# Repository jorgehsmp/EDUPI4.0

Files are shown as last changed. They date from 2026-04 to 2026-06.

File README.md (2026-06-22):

# EDUPI4.0

**PLC educativo, modular y de bajo coste basado en Raspberry Pi Zero 2 W.**

EDUPI4.0 acerca la automatización industrial a aulas, talleres y laboratorios mediante una plataforma abierta que combina entradas de 24 V, salidas por relé, conectividad y una carcasa imprimible en 3D. El repositorio reúne el diseño electrónico, la lista de materiales, el conjunto mecánico y evidencias de su evaluación en el aula.

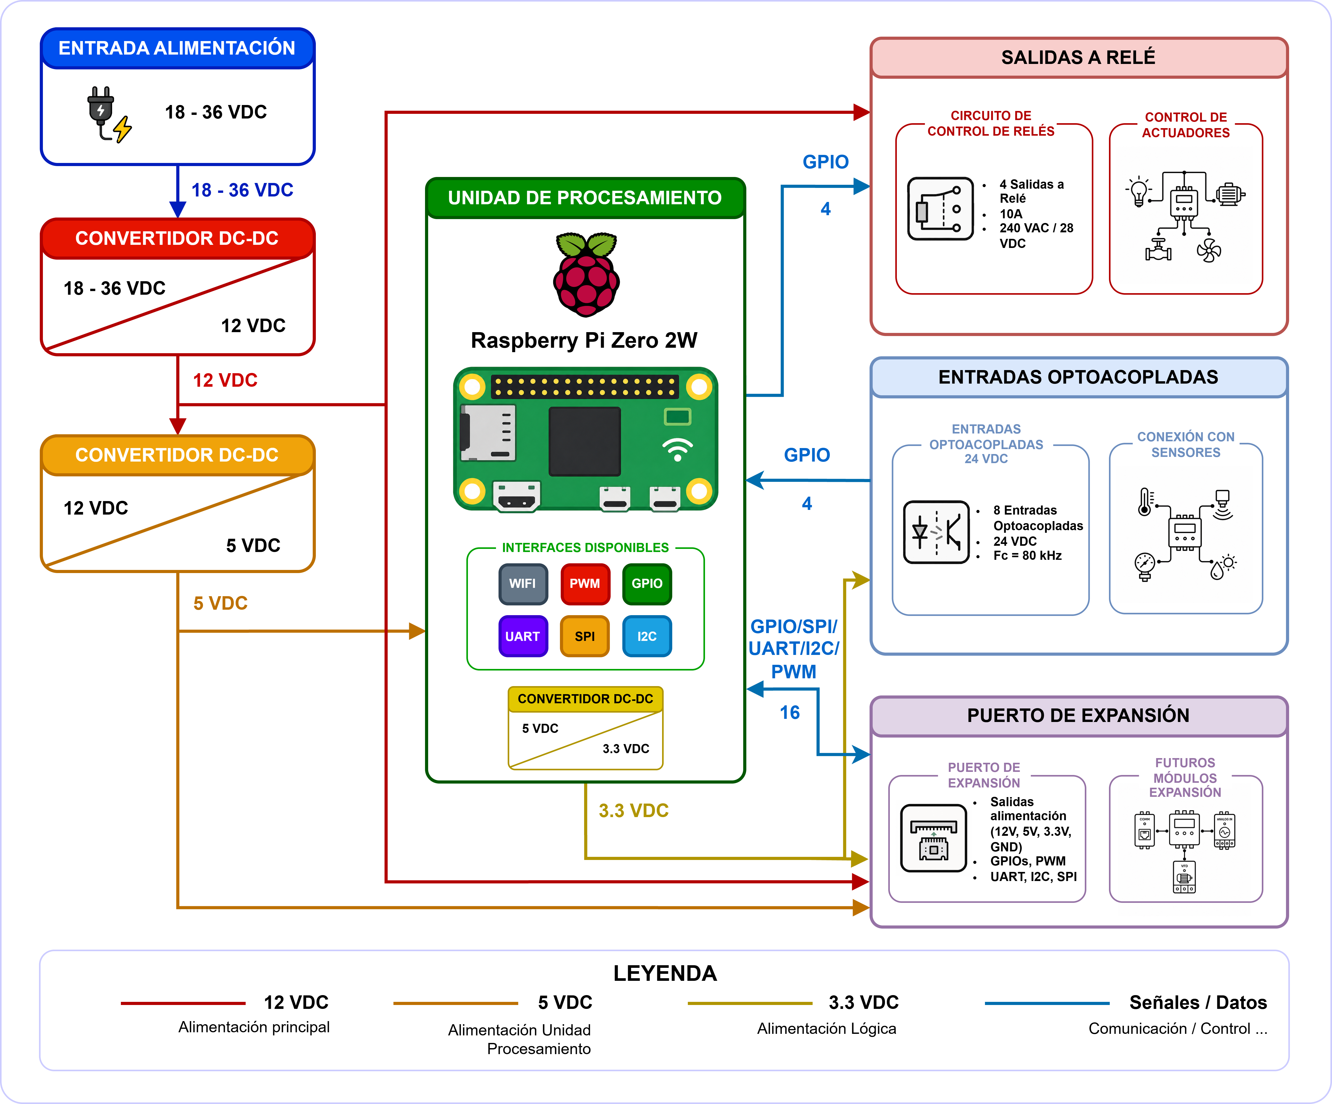
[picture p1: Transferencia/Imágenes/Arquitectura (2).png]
Arquitectura de EDUPI4.0


## Características principales

| Bloque | Especificación |
| --- | --- |
| Unidad de procesamiento | Raspberry Pi Zero 2 W |
| Alimentación de entrada | 18–36 VDC |
| Entradas digitales | 8 entradas optoacopladas para señales de 24 VDC |
| Salidas digitales | 4 relés con contactos NC, COM y NO |
| Capacidad indicada de los relés | Hasta 10 A; 240 VAC o 28 VDC, según el diseño |
| Expansión | 16 señales GPIO/SPI/UART/I²C/PWM y líneas de 12 V, 5 V, 3,3 V y GND |
| Interfaces de la Raspberry Pi | Wi-Fi, GPIO, PWM, UART, SPI e I²C |
| Programación prevista | CODESYS, compatible con lenguajes IEC 61131-3 |
| Coste electrónico estimado | 27,63 € por unidad según la BOM incluida |

La alimentación se convierte internamente de 18–36 VDC a 12 VDC, 5 VDC y 3,3 VDC para los distintos bloques del sistema. Las entradas y el control de los relés incorporan aislamiento mediante optoacopladores.

> [!IMPORTANT]
> Este es un equipo educativo y no un PLC industrial certificado. Trabajar con 230/240 VAC implica riesgo de descarga, incendio y daños materiales. El montaje y las pruebas a tensión de red deben realizarlos personas cualificadas, con protecciones, envolvente y procedimientos adecuados. Verifica siempre el componente montado y sus límites reales antes de conectar una carga.

## Contenido del repositorio

```text
EDUPI4.0/
├── Hardware/
│   └── PLC_Raspberry_EDUPI4.0_FA/      # Proyecto, esquemas, PCB y librerías Altium
├── BOM/
│   └── PLC_Raspberry_EDUPI4.0_FA.xlsx # Lista de materiales y precios de referencia
├── Archivos 3D/
│   └── CARCASA_PLC_EDUPI4.0/          # Inventor, STEP, 3MF y STL de la carcasa
├── Transferencia/
│   └── Imágenes/                       # Diagramas y fotografías para divulgación
├── Evaluación en aula/
│   ├── Formulario alumnos/             # Encuesta, respuestas anonimizadas y PDF
│   └── Imágenes montajes/               # Evidencias de prácticas y montajes
├── LICENSE
└── README.md
```

### Diseño electrónico

El proyecto principal se abre desde [`PLC_Raspberry_Microdesys_FA.PrjPcb`](Hardware/PLC_Raspberry_EDUPI4.0_FA/PLC_Raspberry_Microdesys_FA.PrjPcb) con **Altium Designer**. Incluye:

- esquemáticos jerárquicos y documento de arquitectura;
- PCB actual `PCB_Raspberry_V5.PcbDoc` y revisiones anteriores;
- librerías locales de símbolos y encapsulados;
- configuraciones CAM para Gerber y taladrado NC.

Los archivos Gerber de fabricación no están exportados en el repositorio. Deben generarse desde las configuraciones CAM y revisarse antes de encargar la placa.

### Carcasa

Los archivos fuente mecánicos son de **Autodesk Inventor** (`.ipt` y `.iam`). Para imprimir sin modificar el diseño, utiliza los modelos vigentes de [`Impresión 3D`](Archivos%203D/CARCASA_PLC_EDUPI4.0/Impresión%203D/):

- `INFERIOR.stl`;
- `SUPERIOR v4.stl`;
- `CARCASA_PLC_V6_Tapa v4.stl`;
- `CUBRE EXP v4.stl`;
- `CLIP.stl`.

La subcarpeta `Antiguo` y la carpeta `OldVersions` contienen iteraciones previas y no son la opción recomendada para un montaje nuevo.

### Lista de materiales

La [BOM](BOM/PLC_Raspberry_EDUPI4.0_FA.xlsx) contiene 33 partidas de componentes y una estimación total de **27,63 €**, incluyendo Raspberry Pi Zero 2 W y PCB. Los precios son orientativos: no incluyen necesariamente impuestos, transporte, montaje, carcasa ni herramientas, y pueden variar con el proveedor y el volumen de compra.

### Evaluación educativa

`Evaluación en aula` conserva el formulario empleado con el alumnado, sus respuestas anonimizadas y fotografías de los montajes. Los materiales cubren comprensión y aprendizaje, experiencia práctica, motivación, usabilidad, realismo industrial, valor y accesibilidad.

## Cómo reproducir el proyecto

1. Revisa la arquitectura, los esquemas y las especificaciones de cada componente.
2. Abre el proyecto de Altium y ejecuta las comprobaciones ERC y DRC.
3. Genera y valida Gerbers, archivos de taladrado y documentación de montaje.
4. Actualiza precios, referencias y disponibilidad en la BOM antes de comprar.
5. Fabrica y ensambla la PCB siguiendo prácticas adecuadas de ESD y seguridad eléctrica.
6. Imprime las piezas STL actuales y comprueba ajustes, ventilación y aislamiento.
7. Instala el sistema operativo y el entorno de ejecución elegido en la Raspberry Pi.
8. Configura CODESYS y asigna los GPIO de acuerdo con el esquemático del hardware.
9. Prueba primero con baja tensión y cargas seguras antes de utilizar los contactos de los relés con tensiones peligrosas.

> [!NOTE]
> Este repositorio no incluye actualmente una imagen del sistema, un proyecto CODESYS, ejemplos de aplicación ni un mapa de variables listo para desplegar. La configuración de software debe prepararse y validarse para cada instalación.

## Estado del proyecto

El repositorio contiene fuentes de diseño y material de validación educativa. Antes de fabricar o utilizar una unidad, conviene revisar al menos:

- coherencia entre esquemático, PCB, BOM y componente realmente adquirido;
- reglas eléctricas y de diseño de la revisión V5;
- separación, aislamiento y protecciones para cargas de red;
- pinout y lógica activa de entradas y salidas;
- compatibilidad de versiones entre Raspberry Pi OS y CODESYS.

## Contribuciones

Las incidencias y propuestas son bienvenidas. Para cambios de hardware, indica la revisión afectada y adjunta, cuando corresponda, esquemas, DRC/ERC, Gerbers actualizados y fotografías o resultados de prueba. Evita incluir datos personales en nuevas evidencias de aula.

## Licencia

El contenido se publica bajo la [licencia MIT](LICENSE). Comprueba por separado las licencias y condiciones de uso de modelos CAD, librerías, componentes de terceros y software externo.

## Cita

Si utilizas este trabajo en docencia o investigación, puedes citarlo provisionalmente como:

> *EDUPI4.0: PLC educativo de bajo coste para automatización industrial e Industria 4.0*, 2026.

Sustituye esta referencia por la publicación académica definitiva cuando esté disponible.

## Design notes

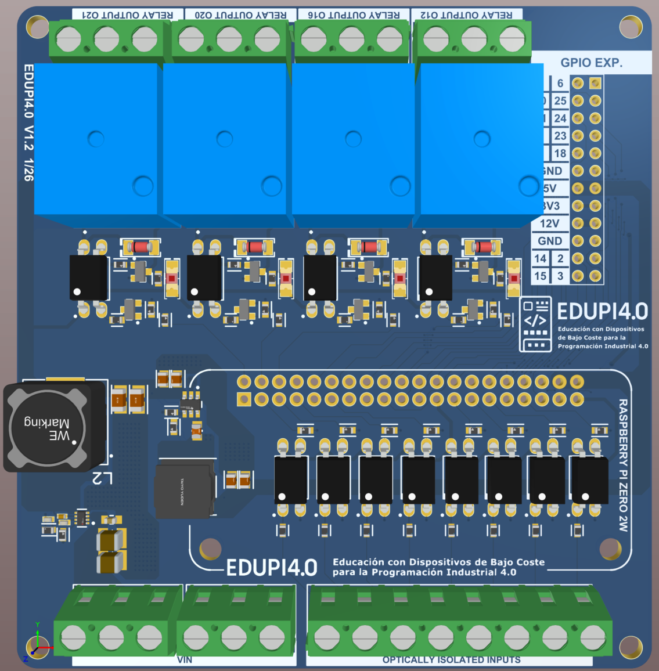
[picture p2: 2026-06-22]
Transferencia/Imágenes/Diseño PCB (1).png

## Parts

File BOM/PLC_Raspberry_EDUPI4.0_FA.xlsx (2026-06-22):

Designator | Description | Comment | Price | Quantity | Total Price
D1, D2, D3, D4, D13, D14, D15, D16, D17, D18, D19, D20 | OPTOISOLATR 5KV TRANSISTOR 4-SMD | LTV-817S-TA | 0.08 | 12 | 0.96
D5, D6, D7, D8 | LED RED CLEAR SMD | LTST-C150EKT | 0.077 | 4 | 0.308
D9, D10, D11, D12 | DIODE GEN PURP 100V 200MA SOD80 | LL4148 | 0.043 | 4 | 0.172
J1, J2, J3, J4 | TERM BLK 3P SIDE ENT 5.08MM PCB | Bloque de terminales 3P 5.08 Verde | 0.08225 | 4 | 0.329
J7 | TERM BLK 3P SIDE ENT 5.08MM PCB | Bloque de terminales 3P 5.08 Rojo | 0.164 | 1 | 0.164
J8 | TERM BLK 3P SIDE ENT 5.08MM PCB | Bloque de terminales 3P 5.08 Negro | 0.164 | 1 | 0.164
J5 | TERM BLK 8P SIDE ENT 5.08MM PCB | Bloque de terminales 2P 5.08 Verde | 0.06725 | 4 | 0.269
J9 | Conn Unshrouded Header HDR 20 POS 2.54mm Solder ST Thru-Hole Box | Conector hembra 2x12 2,54mm 90º | 0.389 | 1 | 0.389
K1, K2, K3, K4 | 5V Trigger Relay Module For Arduino And Raspberry Pi 5V Trigger Relay Module For Arduino And Raspberry Pi | SRD-12VDC-SL-C | 0.398 | 4 | 1.592
Q1, Q2, Q3, Q4, Q5, Q6, Q7, Q8 | General Purpose Transistor, NPN Silicon, 3-Pin SOT-23, Pb-Free, Tape and Reel | SMMBT3904LT1G | 0.042 | 8 | 0.336
R1, R2, R3, R4 | RES Thick Film, 820Ω, 1%, 0.33W, 100ppm/°C, 0603 | RC0603FR-10820RL | 0.003 | 4 | 0.012
R5, R6, R7, R8, R9, R10, R11, R12, R13, R14, R15, R16 | RES Thick Film, 820Ω, 1%, 0.33W, 100ppm/°C, 0603 | RT0603FRE071KL | 0.007 | 12 | 0.084
R17, R18, R19, R20, R21, R22, R23, R24, R25, R26, R27, R28 | MCT0603MD1002BP100 RES SMD 10k OHM 1% 1/8W 0603 | RT0603FRE0710KL | 0.007 | 12 | 0.084
R29, R30, R31, R32, R33, R34, R35, R36 | CRCW06031K50FKEC RES Thick Film, 1.5kΩ, 1%, 0.1W, 100ppm/°C, 0603 | RT0603FRE131K5L | 0.008 | 8 | 0.064
U4 | Raspberry pi zero 2W | Raspberry pi zero 2W | 12.9 | 1 | 12.9
 | Pin header female | Conector macho 2x20 2,54mm | 0.4 | 1 | 0.4
 | PCB | PCB | 4 | 1 | 4
U1 | TPS563200DDCR | TPS563200DDCR | 0.635 | 1 | 0.635
C1, C2 | 10 uF 25 VDC 10% 0805 X5R | GRM21BR61E106KA73L | 0.06 | 2 | 0.12
C3, C4 | 22 uF 10 VDC 20% 0805 X5R | MSASL21GBB5226MTNA01 | 0.084 | 2 | 0.168
C5 | 0,1 uF 25 VDC 10% 0805 X7R | KYOCERA-AVX/08053C104KAT2A | 0.04 | 1 | 0.04
L1 | 3.3uH 30% 4,9A | NRS8040T3R3NJGJ | 0.235 | 1 | 0.235
R37 | 0.125W 56.2Kohms 1% 0603 50ppm Auto | MCT06030C5622FP500 | 0.021 | 1 | 0.021
R38, R40 | 0.1W 10Kohms 1% 0603 50ppm Auto | MCT06030C1002FP500 | 0.021 | 2 | 0.042
U2 | TPS62932DRLR | TPS62932DRLR | 0.743 | 1 | 0.743
C6 | 0.1 uF 10 VDC 10% 0402 X7R | GRM155R71A104KA01D | 0.015 | 1 | 0.015
C7, C8 | 50V 10uF X5R 1210 10 % | MSASU32MSB5106KPNA01 | 0.211 | 2 | 0.422
C9 | CGA 0603 50V 0.1uF X7R 10% | CGA3E2X7R1H104K080AA | 0.026 | 1 | 0.026
C10 | 6.8 pF 25 VDC 0.25 pF 0402 C0G | GRM1555C1E6R8CA01D | 0.016 | 1 | 0.016
C11 | 0.033 uF 10 VDC 10% 0402 X7R | GRM155R71A333KA01D | 0.02 | 1 | 0.02
C12, C13 | 1206 35V 22uF X5R 20% | C3216X5R1V226M160AC | 0.338 | 2 | 0.676
L2 | 22uH 4A 44.5mOhm 4747(1212 metric) | 784770220 | 2.16 | 1 | 2.16
R39 | 140K OHM 1% 1/4W 100PPM | ERJ-PA3F1403V | 0.065 | 1 | 0.065
 |  |  |  | Total | 27.631

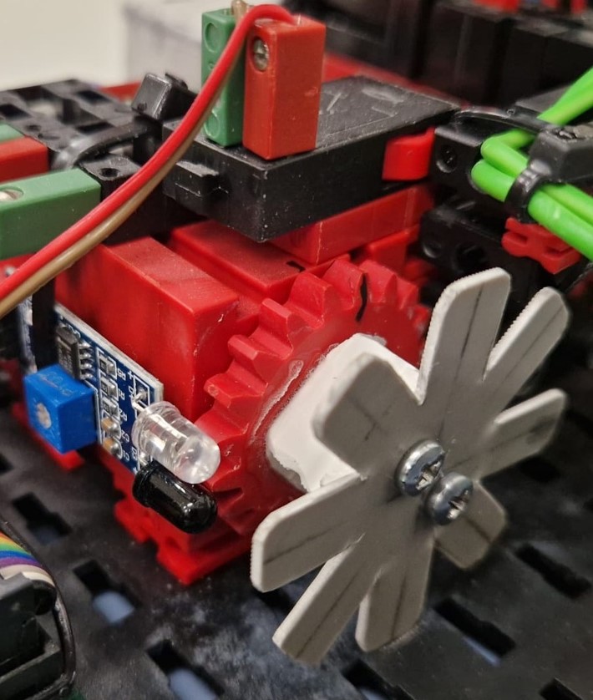
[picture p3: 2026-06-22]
Evaluación en aula/Imágenes montajes/encoderLowCost.jpg

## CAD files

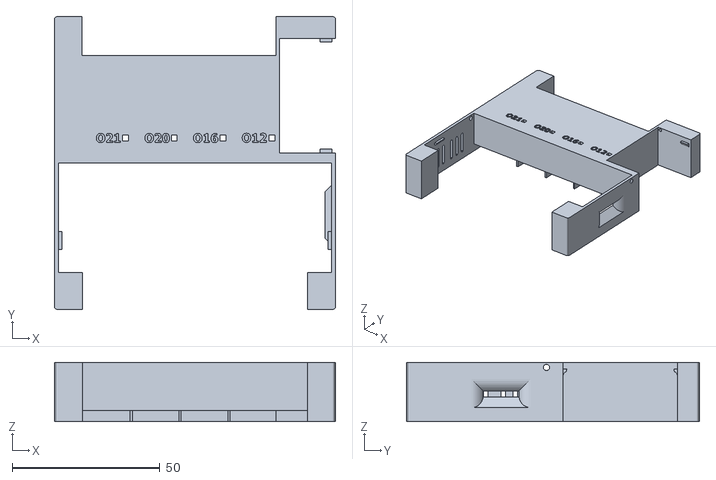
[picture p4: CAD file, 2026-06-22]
Archivos 3D/CARCASA_PLC_EDUPI4.0/Impresión 3D/SUPERIOR v4.stl
95.0 x 99.0 x 20.0

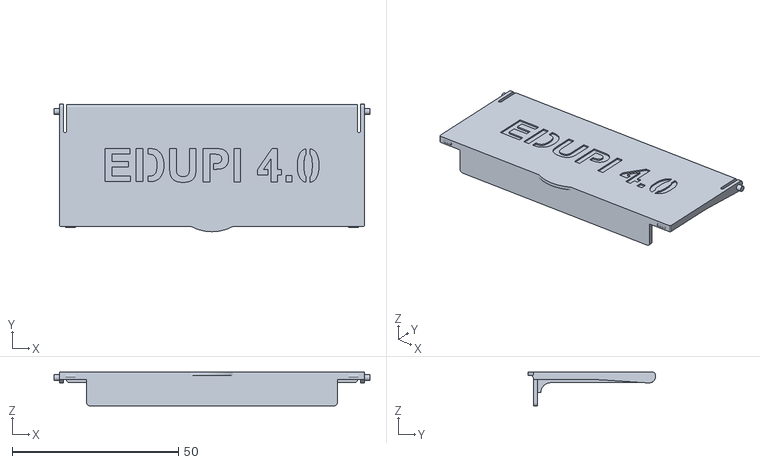
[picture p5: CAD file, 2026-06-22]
Archivos 3D/CARCASA_PLC_EDUPI4.0/Impresión 3D/CARCASA_PLC_V6_Tapa v4.stl
95.0 x 38.3 x 10.2

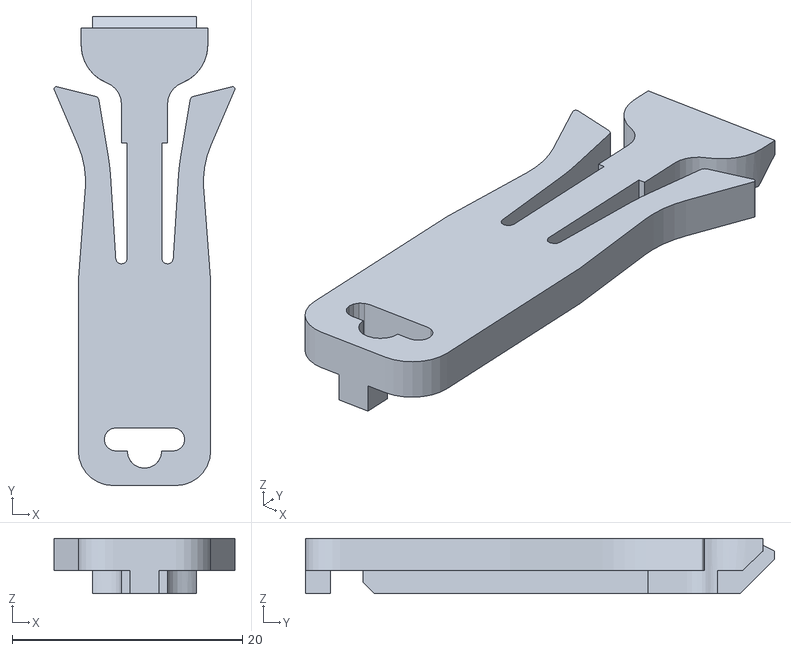
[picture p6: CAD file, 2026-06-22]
Archivos 3D/CARCASA_PLC_EDUPI4.0/Impresión 3D/CLIP.stl
15.7 x 40.8 x 4.80

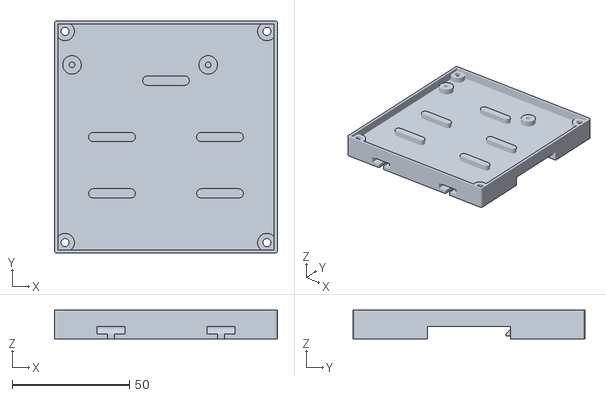
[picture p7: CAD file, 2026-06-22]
Archivos 3D/CARCASA_PLC_EDUPI4.0/Impresión 3D/INFERIOR.stl
95.0 x 99.0 x 12.3

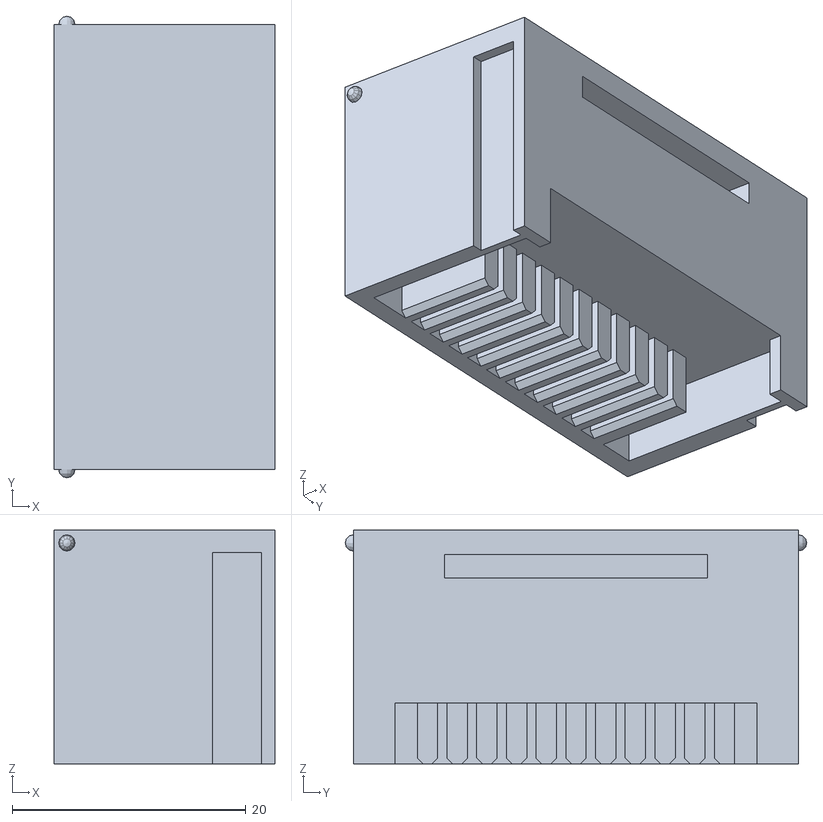
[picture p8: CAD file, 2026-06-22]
Archivos 3D/CARCASA_PLC_EDUPI4.0/Impresión 3D/CUBRE EXP v4.stl
18.9 x 39.5 x 20.0

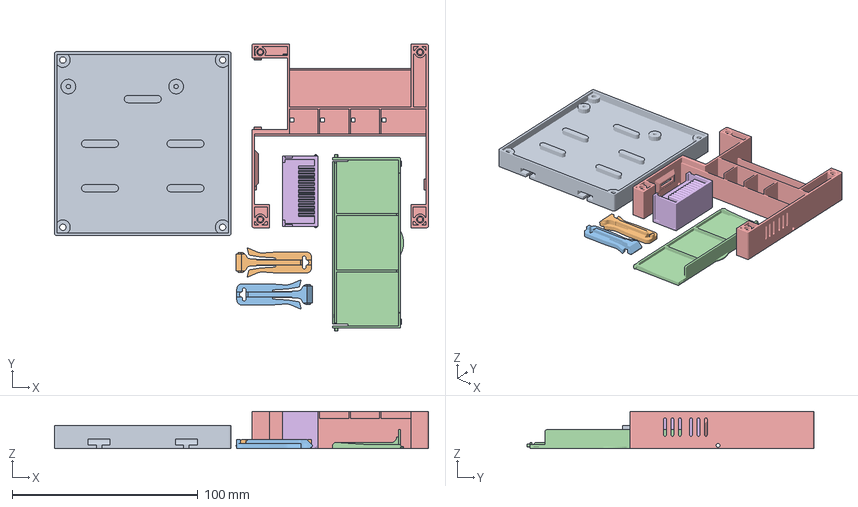
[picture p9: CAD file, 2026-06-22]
Archivos 3D/CARCASA_PLC_EDUPI4.0/Impresión 3D/impresión carcasa PLC EDUPI.3mf
201.3 x 154.6 x 20.0 mm
INFERIOR.stl
CLIP.stl x 2
CARCASA_PLC_V6_Tapa v4.stl
SUPERIOR v4.stl
CUBRE EXP v4.stl

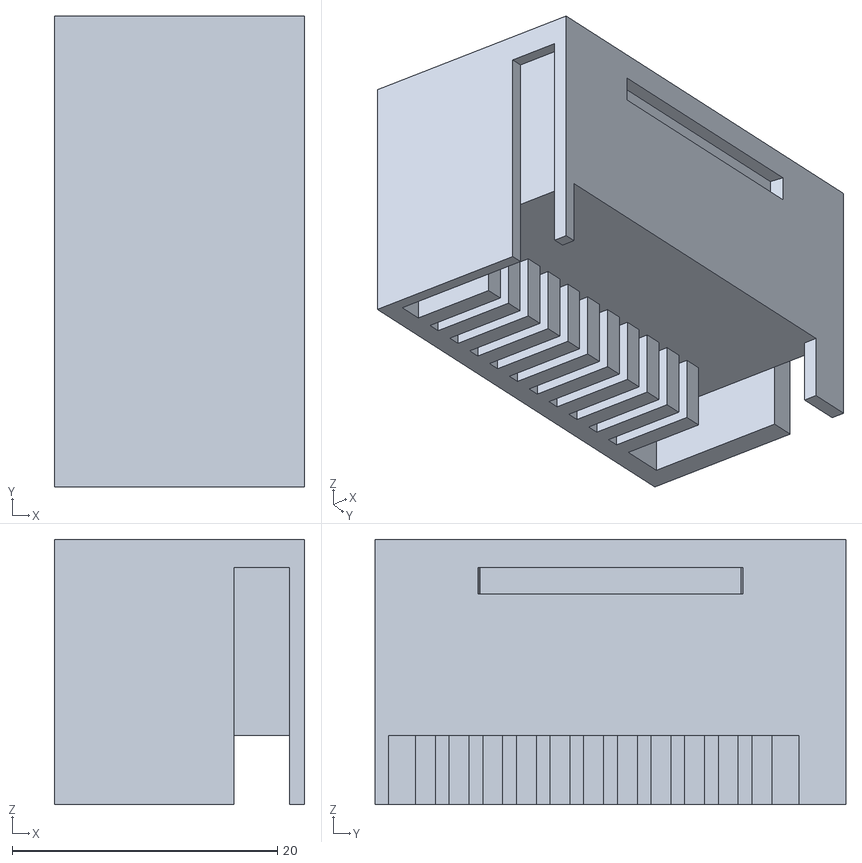
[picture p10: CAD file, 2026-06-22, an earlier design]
Archivos 3D/CARCASA_PLC_EDUPI4.0/Impresión 3D/Antiguo/CUBRE EXP v2.stl
18.9 x 35.5 x 20.0

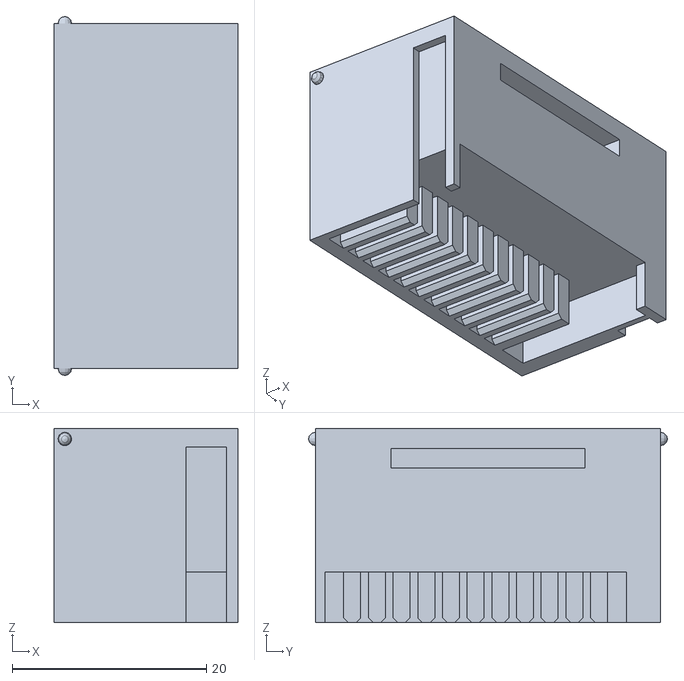
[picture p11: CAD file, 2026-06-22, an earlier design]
Archivos 3D/CARCASA_PLC_EDUPI4.0/Impresión 3D/Antiguo/CUBRE EXP v2.7.stl
18.9 x 36.9 x 20.0

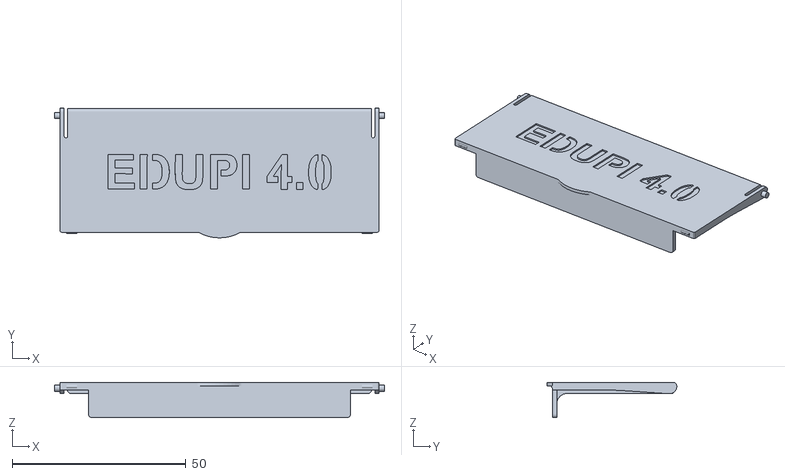
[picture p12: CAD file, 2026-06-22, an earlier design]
Archivos 3D/CARCASA_PLC_EDUPI4.0/Impresión 3D/Antiguo/CARCASA_PLC_V6_Tapa v3.stl
95.0 x 37.3 x 10.2

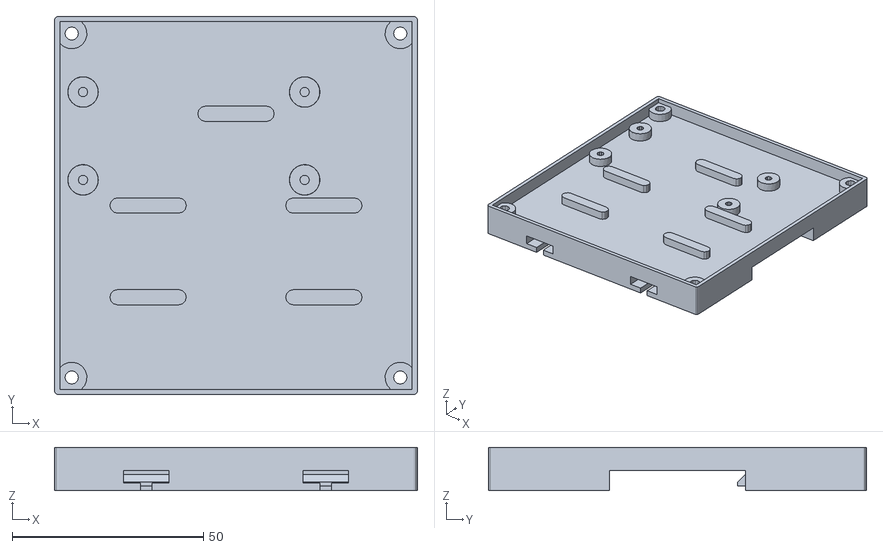
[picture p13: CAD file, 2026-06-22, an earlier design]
Archivos 3D/CARCASA_PLC_EDUPI4.0/Impresión 3D/Antiguo/INFERIOR v2.6.stl
95.0 x 99.0 x 11.3

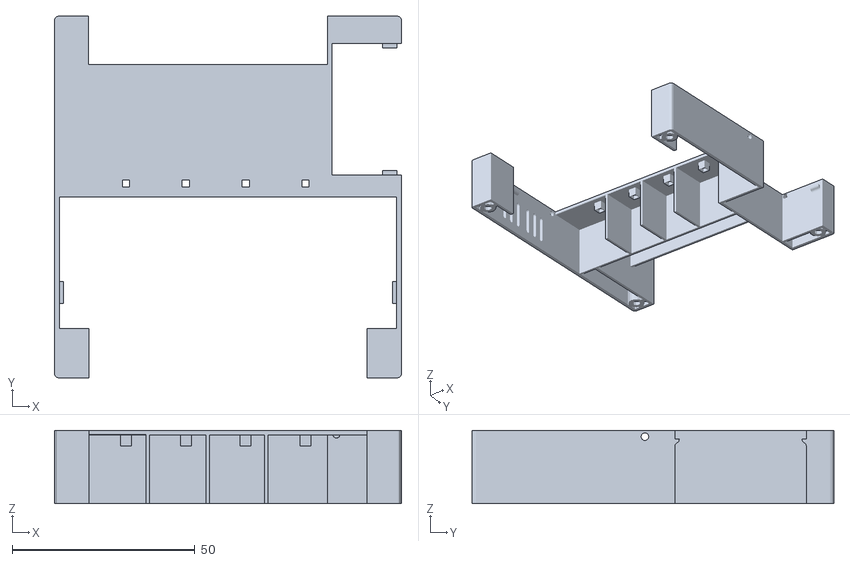
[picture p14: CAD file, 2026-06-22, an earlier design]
Archivos 3D/CARCASA_PLC_EDUPI4.0/Impresión 3D/Antiguo/SUPERIOR v2.stl
95.0 x 99.0 x 20.0

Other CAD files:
Archivos 3D/CARCASA_PLC_EDUPI4.0/Impresión 3D/Antiguo/CUBRE EXP v2.6.stl
Archivos 3D/CARCASA_PLC_EDUPI4.0/Impresión 3D/Antiguo/INFERIOR v2.7.stl
Archivos 3D/CARCASA_PLC_EDUPI4.0/Impresión 3D/Antiguo/SUPERIOR v2.6.stl
Archivos 3D/CARCASA_PLC_EDUPI4.0/Impresión 3D/Antiguo/SUPERIOR v2.5.stl
Archivos 3D/CARCASA_PLC_EDUPI4.0/Impresión 3D/Antiguo/INFERIOR v2.stl
Archivos 3D/CARCASA_PLC_EDUPI4.0/Impresión 3D/Antiguo/SUPERIOR v2.7.stl
Archivos 3D/CARCASA_PLC_EDUPI4.0/0204 - Capacitor Brown.ipt
Archivos 3D/CARCASA_PLC_EDUPI4.0/0204 - Capacitor.ipt
Archivos 3D/CARCASA_PLC_EDUPI4.0/0204- Resistor.ipt
Archivos 3D/CARCASA_PLC_EDUPI4.0/0805- Capacitor.ipt
Archivos 3D/CARCASA_PLC_EDUPI4.0/1.ipt
Archivos 3D/CARCASA_PLC_EDUPI4.0/1210 inductor.ipt
Archivos 3D/CARCASA_PLC_EDUPI4.0/2.ipt
Archivos 3D/CARCASA_PLC_EDUPI4.0/2x11 Male Pin Header.ipt
Archivos 3D/CARCASA_PLC_EDUPI4.0/3.ipt
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

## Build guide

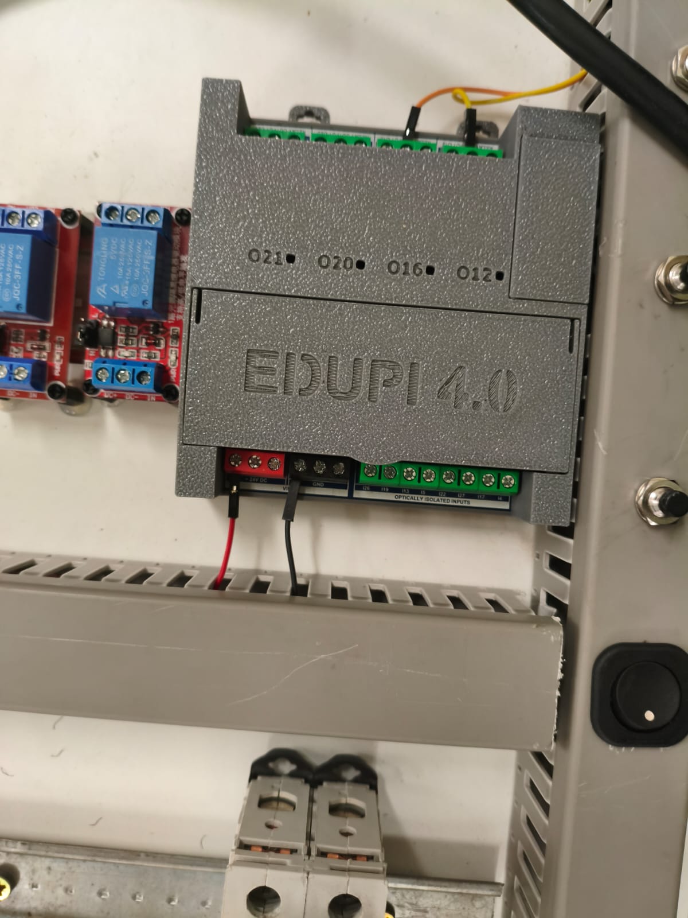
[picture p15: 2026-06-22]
Evaluación en aula/Imágenes montajes/WhatsApp Image 2026-06-16 at 11.55.54.jpeg

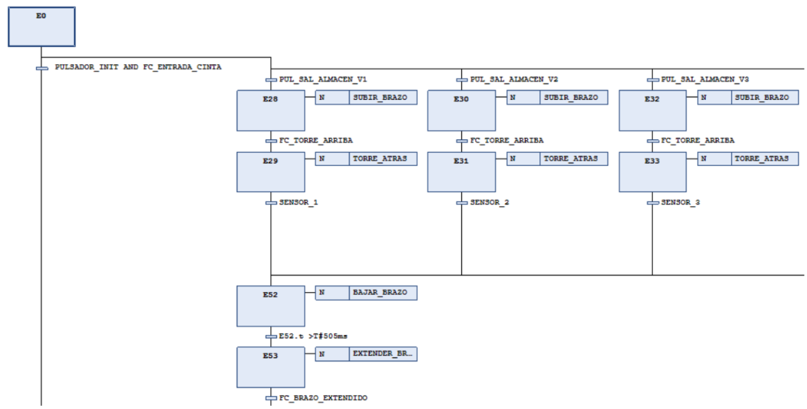
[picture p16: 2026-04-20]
Evaluación en aula/Imágenes montajes/Screenshot_9.png

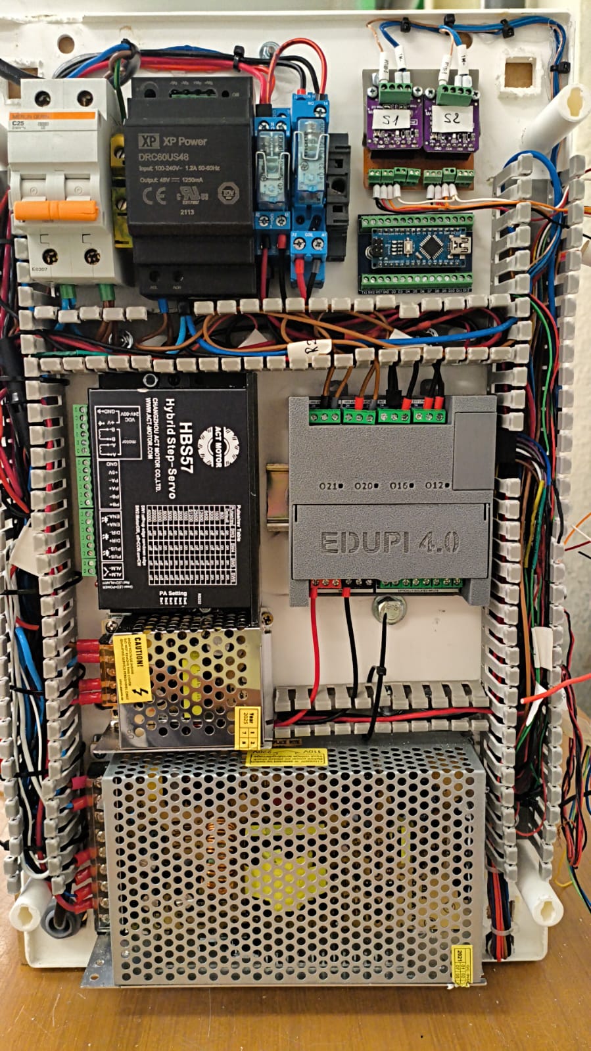
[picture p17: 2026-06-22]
Transferencia/Imágenes/Montaje.jpeg

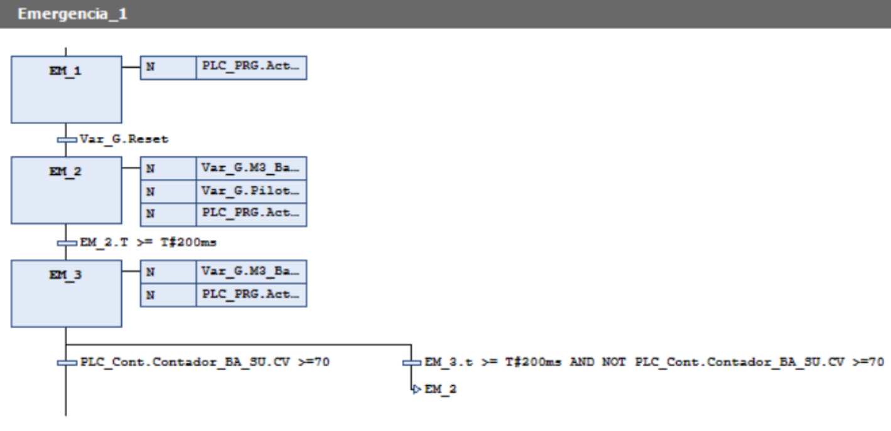
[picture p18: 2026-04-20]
Evaluación en aula/Imágenes montajes/Screenshot_6.png

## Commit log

2026-06-22 Añadir diseño electrónico del hardware
    [1-826656-0.SchLib, Architecture.SchDoc, Conector_Raspberry.PcbLib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]
2026-06-22 Completar renombrado de la carpeta de hardware
    [1-826656-0.SchLib, Architecture.SchDoc, Conector_Raspberry.PcbLib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]
